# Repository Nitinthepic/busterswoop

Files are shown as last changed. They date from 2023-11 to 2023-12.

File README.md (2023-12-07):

# Busterswoop

Fully assembled Busterswoop

A WIP fork of [SuperFola's Arkenswoop](https://github.com/SuperFola/arkenswoop),
which is a fork of [jimmerricks's Swoop](https://github.com/jimmerricks/swoop),
which is a fork of [David Barr's Sweep](https://github.com/davidphilipbarr/Sweep),
which is itself based on the fabulous [Ferris by Pierre Chevalier](https://github.com/pierrechevalier83/ferris).

| Front | Back |
| :---: | :---: |
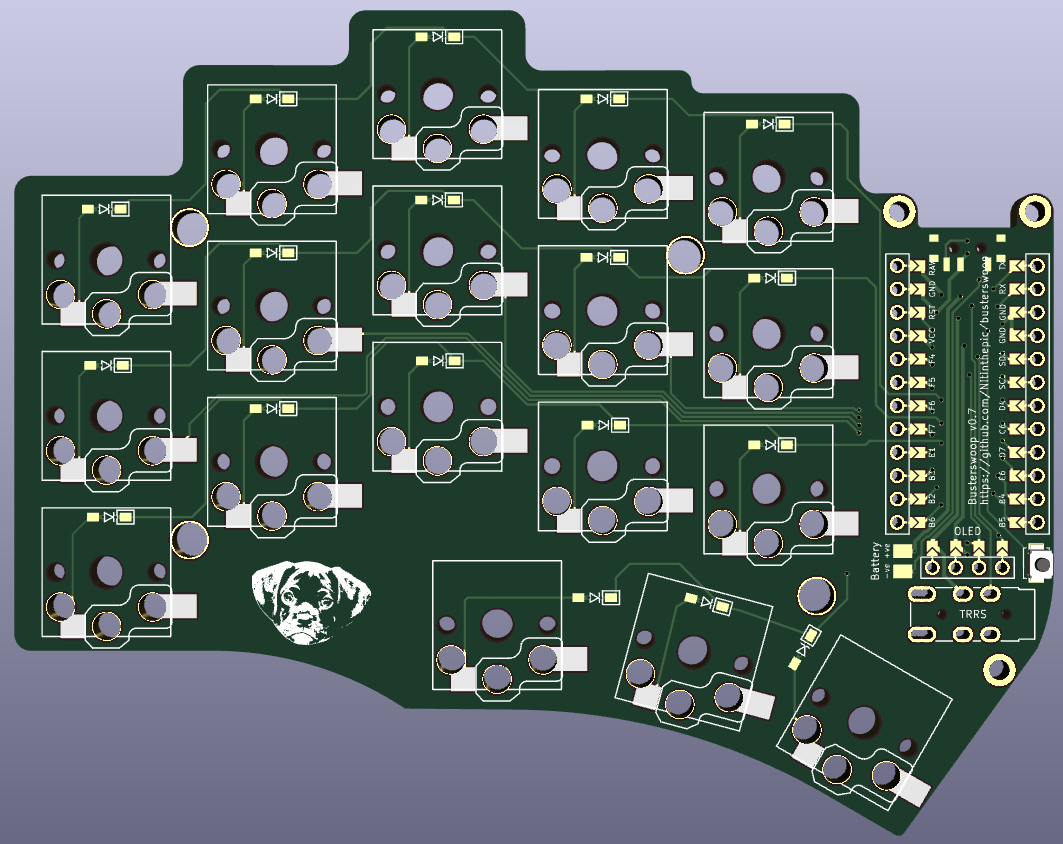
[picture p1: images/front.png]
front
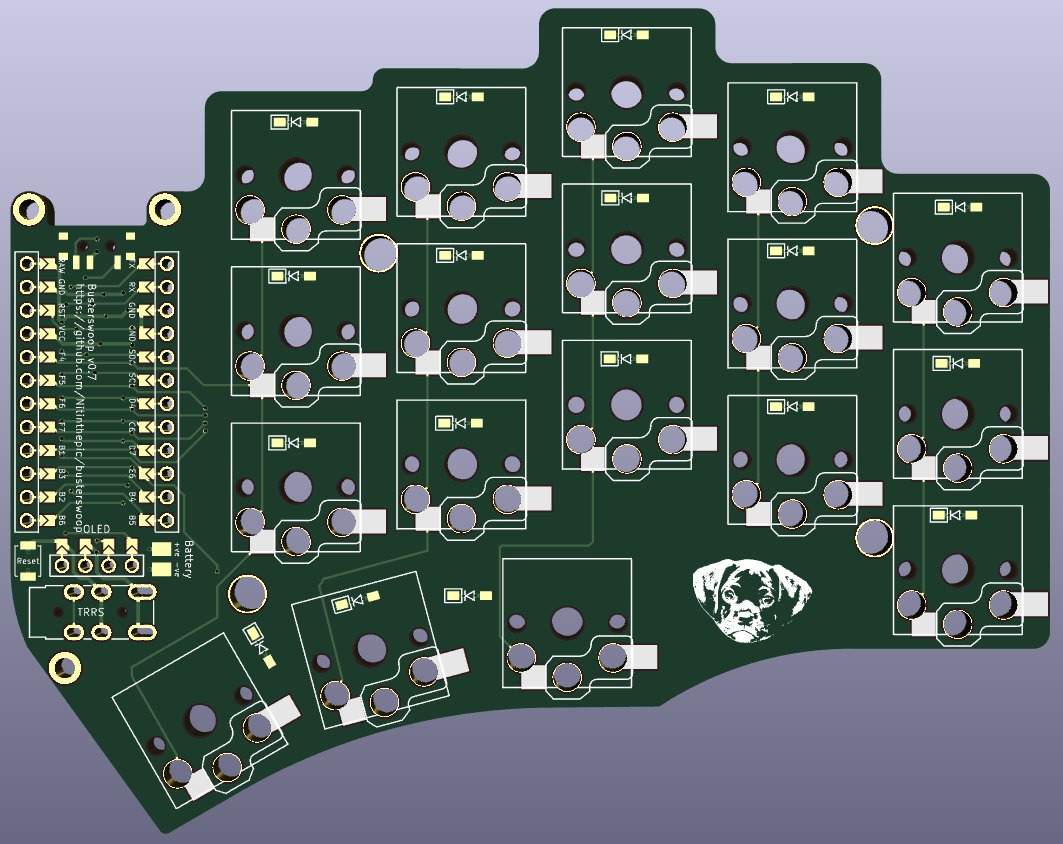
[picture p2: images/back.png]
back
|  |  |

### Features

⭕ Low profile Kailh Choc switches  
⭕ Hotswap  
⭕ Oled screens  
⭕ Power switch for battery management  
⭕ Bluetooth support w/ nice!nano  
⭕ 3D cased assembled with M2 screws 

### Components list

To build and use an Busterswoop you will need:

* 1× PCB Kit (1.6mm thickness when ordering)
* 2× promicro compatible boards or 2 nice!nanos.
* 36× Kailh Choc v1 switches
* 36× Kailh Choc hotswap sockets (PG1350)
* 36× keycaps
* 1-2× OLED LCD Display 128x32 SSD1306 (optional)
* 1-2x Female 4-Pin Headers (optional)
* 4 or 8x Male Header Pins (optional)
* 2× reset switches (optional; B3U-1000P(M))
* Some little rubber feet/bumpers (minimum of 4 on each side)
* 2× power switches (wireless only; MSK 12C02)
* 2× lipo batteries (wireless only; 301230 or 301228)
* 1× TRRS (not TRS!) cable (wired only)
* 2× TRRS Jack [PJ-320A] (wired only)
* 1× USB Cable

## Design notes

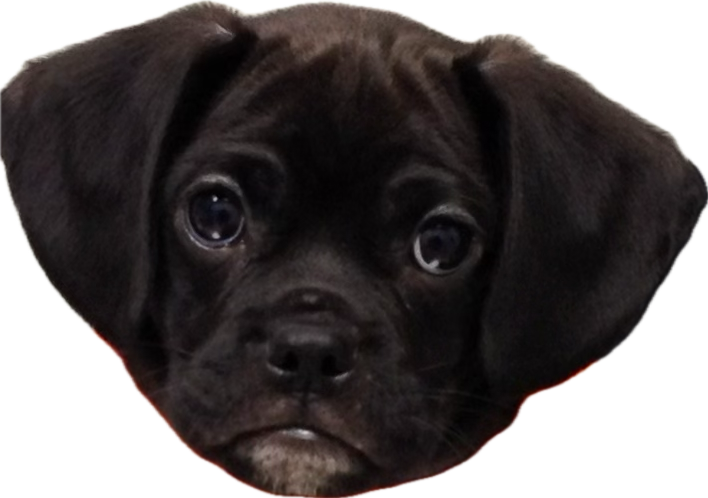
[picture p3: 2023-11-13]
images/Pasted Graphic.png

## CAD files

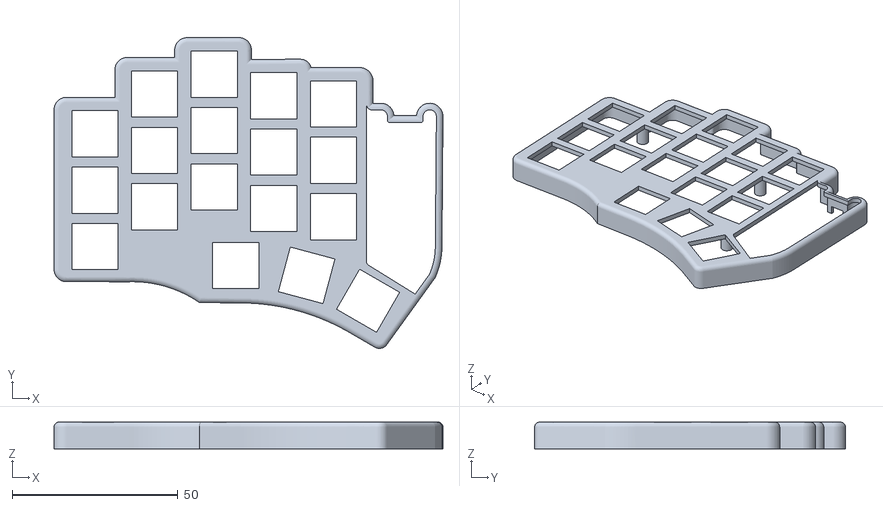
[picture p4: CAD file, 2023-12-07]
stls/busterswoop_top_left.stl
117.4 x 93.8 x 8.10

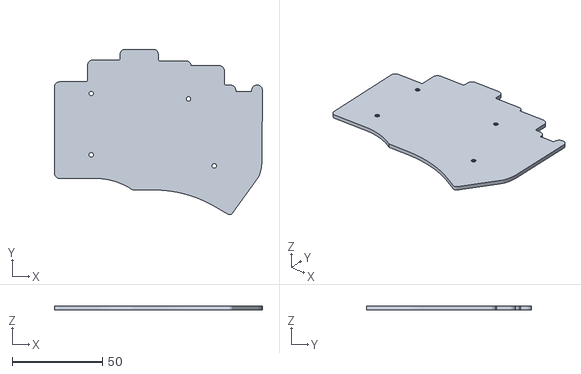
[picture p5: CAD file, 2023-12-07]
stls/busterswoop_bottom_left.stl
115.4 x 91.8 x 2.00

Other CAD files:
stls/busterswoop_top_right.stl
stls/busterswoop_bottom_right.stl

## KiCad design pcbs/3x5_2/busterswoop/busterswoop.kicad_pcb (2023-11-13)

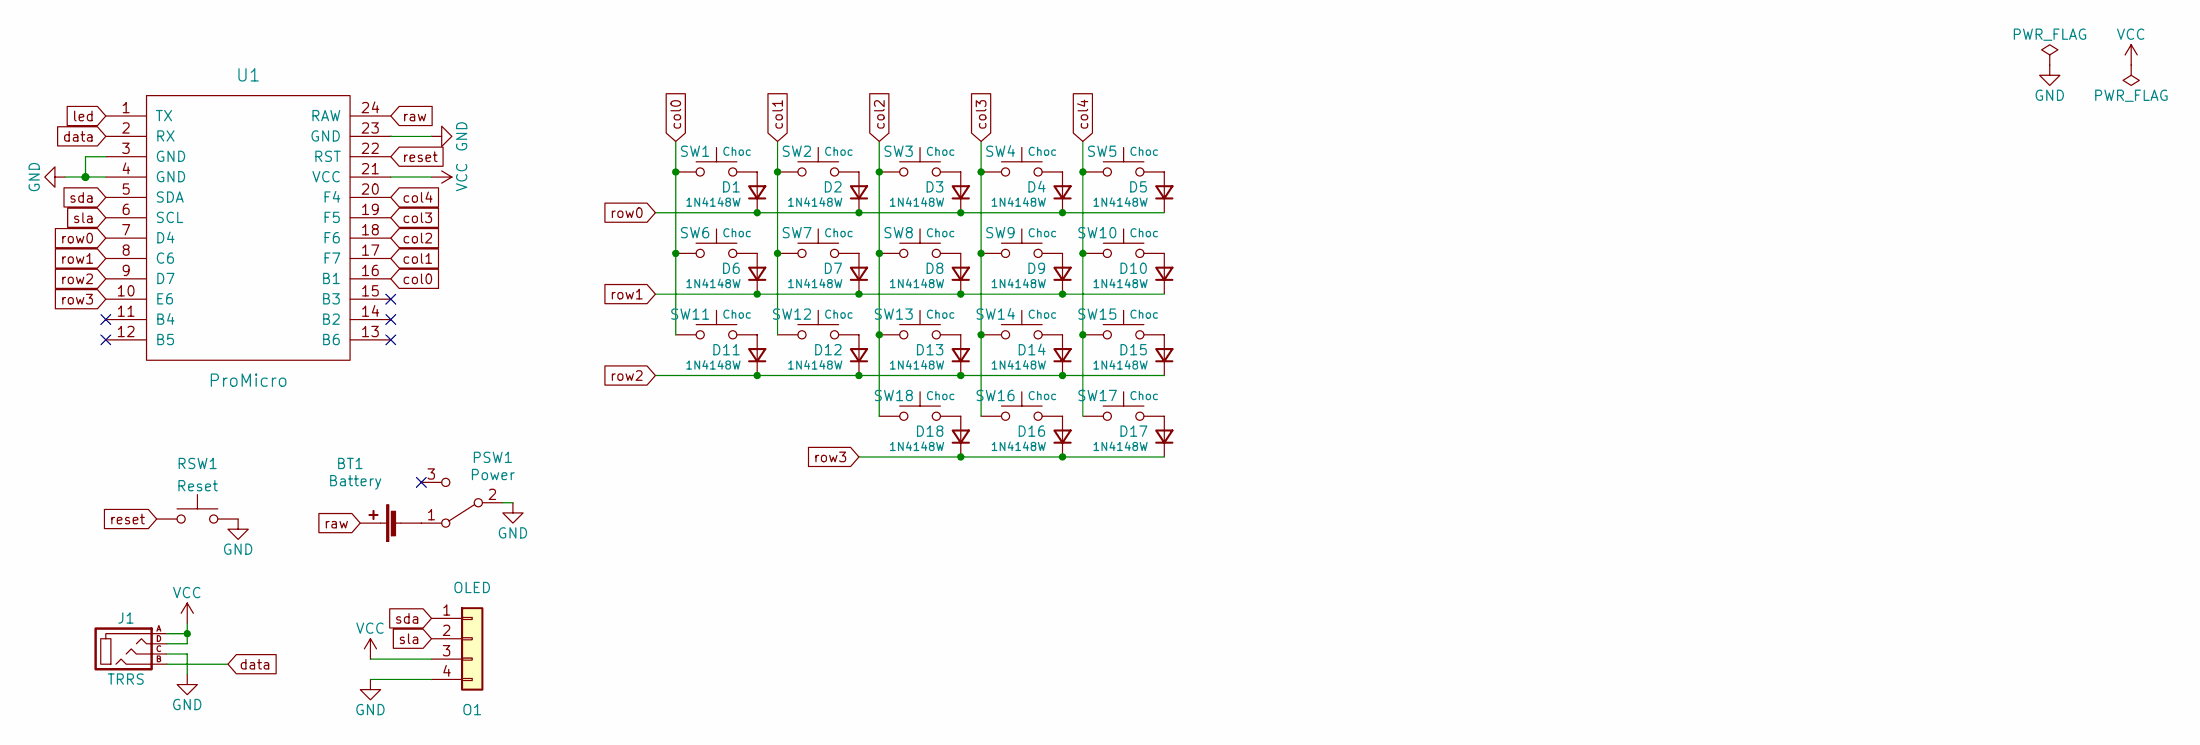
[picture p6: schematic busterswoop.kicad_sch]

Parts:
BT1: Battery; Battery_pads_reversible
D1, D2, D3, D4, D5, D6, D7, D8, D9, D10, D11, D12, D13, D14, D15, D16, D17, D18: 1N4148W; D3_SMD
J1: TRRS; TRRS-3pin
O1: OLED; OLED_jumpers
PSW1: Power
RSW1: Reset
SW1, SW2, SW3, SW4, SW5, SW6, SW7, SW8, SW9, SW10, SW11, SW12, SW13, SW14, SW15, SW16, SW17, SW18: Choc; Kailh-pg1350-socket-reversible
U1: ProMicro; ProMicro_jumpers

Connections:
GND: J1.C, O1.4, PSW1.2 (B), RSW1.2, U1.3 (GND), U1.4 (GND), U1.23 (GND)
unnamed: BT1.2 (-), PSW1.1 (A)
unnamed: D1.2 (A), SW1.2
unnamed: D2.2 (A), SW2.2
unnamed: D3.2 (A), SW3.2
unnamed: D4.2 (A), SW4.2
unnamed: D5.2 (A), SW5.2
unnamed: D6.2 (A), SW6.2
unnamed: D7.2 (A), SW7.2
unnamed: D8.2 (A), SW8.2
unnamed: D9.2 (A), SW9.2
unnamed: D10.2 (A), SW10.2
unnamed: D11.2 (A), SW11.2
unnamed: D12.2 (A), SW12.2
unnamed: D13.2 (A), SW13.2
unnamed: D14.2 (A), SW14.2
unnamed: D15.2 (A), SW15.2
unnamed: D16.2 (A), SW16.2
unnamed: D17.2 (A), SW17.2
unnamed: D18.2 (A), SW18.2
VCC: J1.A, J1.D, O1.3, U1.21 (VCC)
col0: SW1.1, SW6.1, SW11.1, U1.16 (B1)
col1: SW2.1, SW7.1, SW12.1, U1.17 (F7)
col2: SW3.1, SW8.1, SW13.1, SW18.1, U1.18 (F6)
col3: SW4.1, SW9.1, SW14.1, SW16.1, U1.19 (F5)
col4: SW5.1, SW10.1, SW15.1, SW17.1, U1.20 (F4)
data: J1.B, U1.2 (RX)
led: U1.1 (TX)
raw: BT1.1 (+), U1.24 (RAW)
reset: RSW1.1, U1.22 (RST)
row0: D1.1 (K), D2.1 (K), D3.1 (K), D4.1 (K), D5.1 (K), U1.7 (D4)
row1: D6.1 (K), D7.1 (K), D8.1 (K), D9.1 (K), D10.1 (K), U1.8 (C6)
row2: D11.1 (K), D12.1 (K), D13.1 (K), D14.1 (K), D15.1 (K), U1.9 (D7)
row3: D16.1 (K), D17.1 (K), D18.1 (K), U1.10 (E6)
sda: O1.1, U1.5 (SDA)
sla: O1.2, U1.6 (SCL)

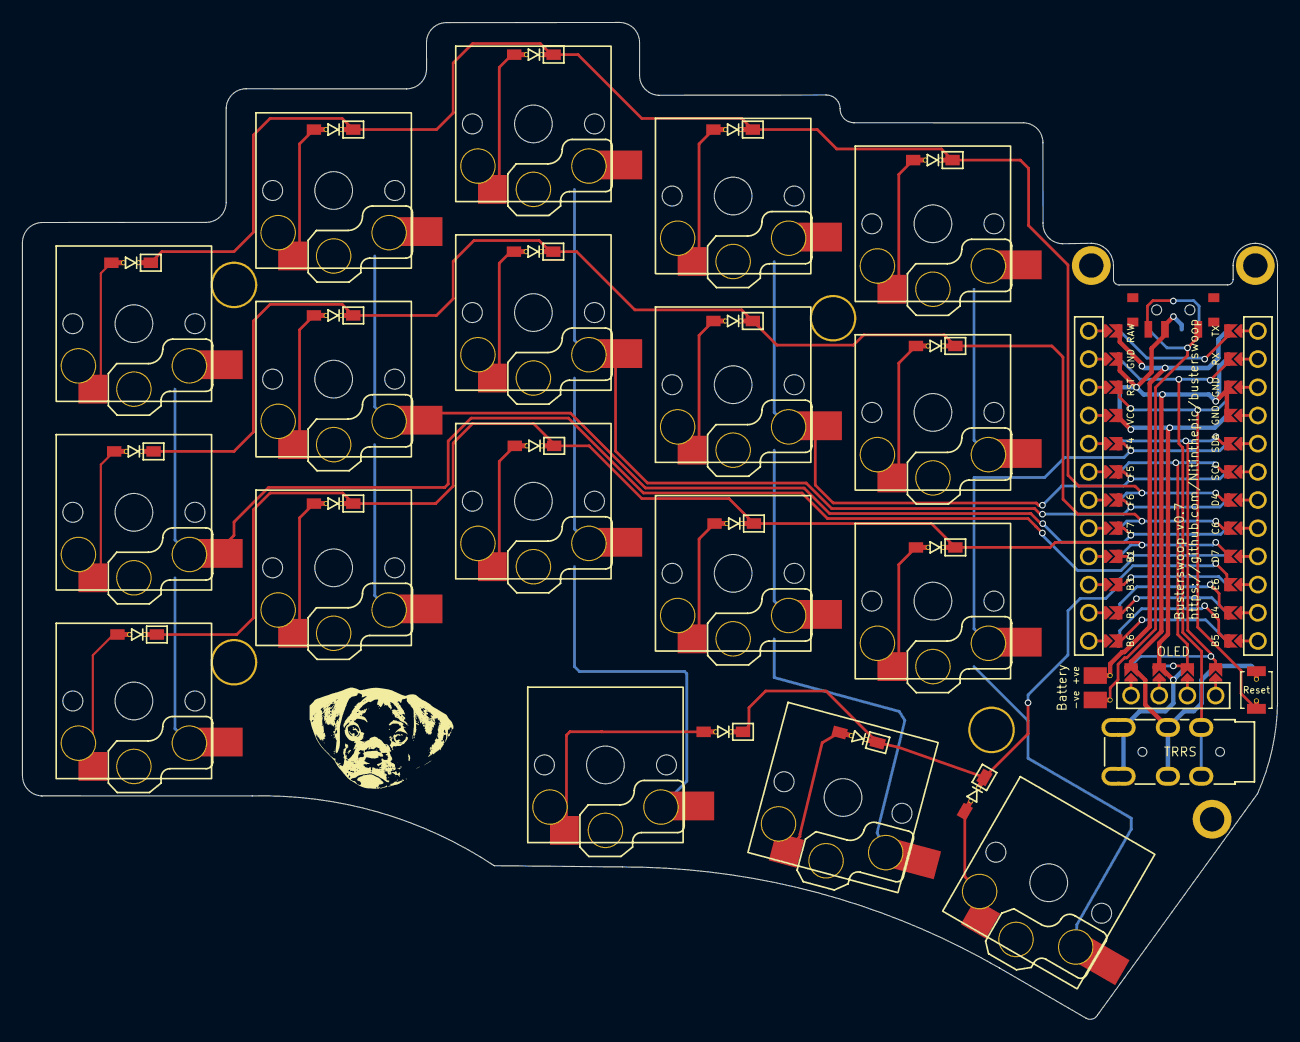
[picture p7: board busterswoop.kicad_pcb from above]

Board: 2 copper layers, 113.1 x 89.8 mm, 49 parts (1 on the bottom side), 35 nets.

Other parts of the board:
H1, H2, H3, H4: M2 Hole; M2_hole_4.2mm
Ref**: Val**; M2_hole_3.5mm
Ref**#2, Ref**#3: Val**; M2_hole_3.5mm

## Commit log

2023-11-13 First Big Commit I have added in the new thumb key, updated the schematic and footprints to match Kailh choc reversibles I have also finished modelling 3D cases for the keyboard, added a silkscreen o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
    [altenswoop.kicad_pcb, altenswoop.kicad_sch, arkenswoop.kicad_pcb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]
2023-12-07 added new stls and images
    [busterswoop.kicad_sch, busterswoop_bottom_left.stl, busterswoop_bottom_right.stl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]
2023-12-07 added new images and rotated finished build
    [bottom_left.stl, bottom_right.stl, top_left.stl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]
